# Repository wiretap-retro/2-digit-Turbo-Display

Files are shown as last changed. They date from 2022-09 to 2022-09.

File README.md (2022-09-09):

# 2 digit Turbo Display
This project is a ATTiny85-based turbo display for retro PC's. It displays 2 digits, for use in 8088 to 486 systems.

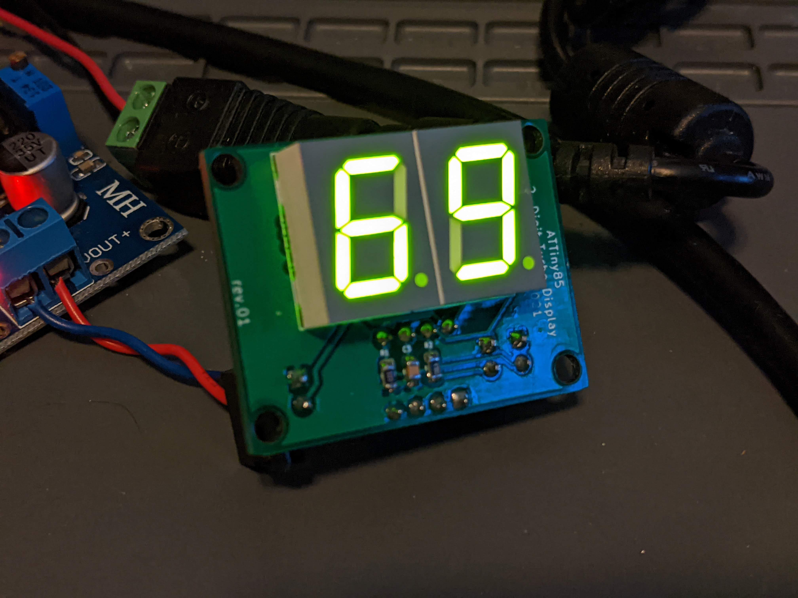
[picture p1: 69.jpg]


## Intro
I was wanting to do an ATTiny85 project and came up with a small 2-digit turbo display for use in my Intel 486 retro gaming PC. This design is pretty simple, easy to build and easy to program. If you have a dead turbo display or your case is missing one, this might be the right fit, as I have tested it on 3 different cases I have and it fits perfect into all of them. Mounting holes are different in nearly every case, so another mounting method may be necessary depending on your situation.
<br /><br />
Demo Video: https://youtu.be/Jka8PfParP4

## Building
* Order the PCB through your PCB fab of choice. (JLCPCB, PCBway, OSH Park, etc.)
* Order the components as listed in the BOM. Substitutions may be necessary depending on the chip/component shortages.
* On the back side and front side, solder the surface mount components first. Pay close attention to the orientation of the SOIC chips, as they are reversed from each other on the right and left.
* On the back side, solder the through-hole components next. I recommend using a socket for the ATTiny85 so you can easily install/remove it for programming.
* On the front side, solder the LED 7-segment displays.
* Soldering complete. Go to the Programming section below.

## Programming
I have included the turbo.ino file as an example. In the main program loop, you can change the "normal" and "turbo" variables to any 2 digit number to match the needs of your particular CPU speeds. The code is pretty well commented, so you can play around with it, adjust delays, make a startup animation, etc. To program the ATTiny85, you can look at one of the hundreds of guides online. For mine, I used a breadboard and another Arduino to do so. After it is programmed, place it in the DIP-8 socket of the turbo display PCB.

## Installation
* As noted in the intro section, this was designed to fit in the Baby-AT cases I have. It seems there was no standard back in the day for making these turbo displays or mounting them, so each case can be different. The digit size fits all mine that have 2-digit display holes, and at least one mounting hole fits on two of the cases. Only one screw is really necessary anyway since it is so small and light. You can secure it in your case with various methods. (tape, blu tack, 3d printed clip, etc.)
* Once mounted in the case, connect the 5V power to a Berg/Molex-->2x2.54mm header. 
* Connect the Turbo LED on your case to the TLED OUT pins.
* Use a female to female cable with 2x2.54mm connectors at each end to connect the motherboard's Turbo LED pins to the turbo display board's TLED IN. These are commonly found on Aliexpress, Amazon, and Ebay for use in Arduino/RPi projects.
* The turbo switch on your case should be connected to the computer's motherboard Turbo Switch pins.
* Turn on the PC and test it out!

## Design Notes
The design takes into account that your motherboard has turbo LED pins to drive switching of this display. I found this to be the most common feature among all motherboards, from the 8088 to 486. I probably own 25 different boards of this era, and they all have the pins to drive a turbo LED. This is the most universal design I could come up with.

## Other
This is an open source project. Feel free to do what you want with it.

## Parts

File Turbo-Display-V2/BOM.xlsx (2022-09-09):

ref | value | footprint | description
C1, C2 | 0.1uF | Capacitor_SMD:C_1206_3216Metric_Pad1.42x1.75mm_HandSolder | Unpolarized capacitor
C3 | 0.1uF | Capacitor_SMD:C_0805_2012Metric_Pad1.15x1.40mm_HandSolder | Unpolarized capacitor
DS1, DS2 | TDSG5150-N | TDSG5150N | LED Displays & Accessories 7-Seg Green 13 mm Common anode
J1, J2, J3 | 2x1 Pin Header | Connector_PinHeader_2.54mm:PinHeader_1x02_P2.54mm_Vertical | Generic connector, single row, 01x02, script generated (kicad-library-utils/schlib/autogen/connector/)
R1 | 10k | Resistor_SMD:R_0805_2012Metric_Pad1.15x1.40mm_HandSolder | Resistor
R2 | 470 | Resistor_SMD:R_0805_2012Metric_Pad1.15x1.40mm_HandSolder | Resistor
RN1, RN2 | 4816P-T01-471LF | SOIC127P762X240-16N | Res Thick Film NET 470 Ohm 2% 1.28W +/-100ppm/C ISOL Molded 16-Pin SOM Gull Wing SMD Automotive Tube
U1 | ATtiny85 | Package_DIP:DIP-8_W7.62mm | 20MHz, 8kB Flash, 512B SRAM, 512B EEPROM, debugWIRE, DIP-8
U2, U3 | SN74HC595DR | SamacSys_Parts:SOIC127P600X175-16N | 8-bit serial in/out Shift Register 3-State Outputs

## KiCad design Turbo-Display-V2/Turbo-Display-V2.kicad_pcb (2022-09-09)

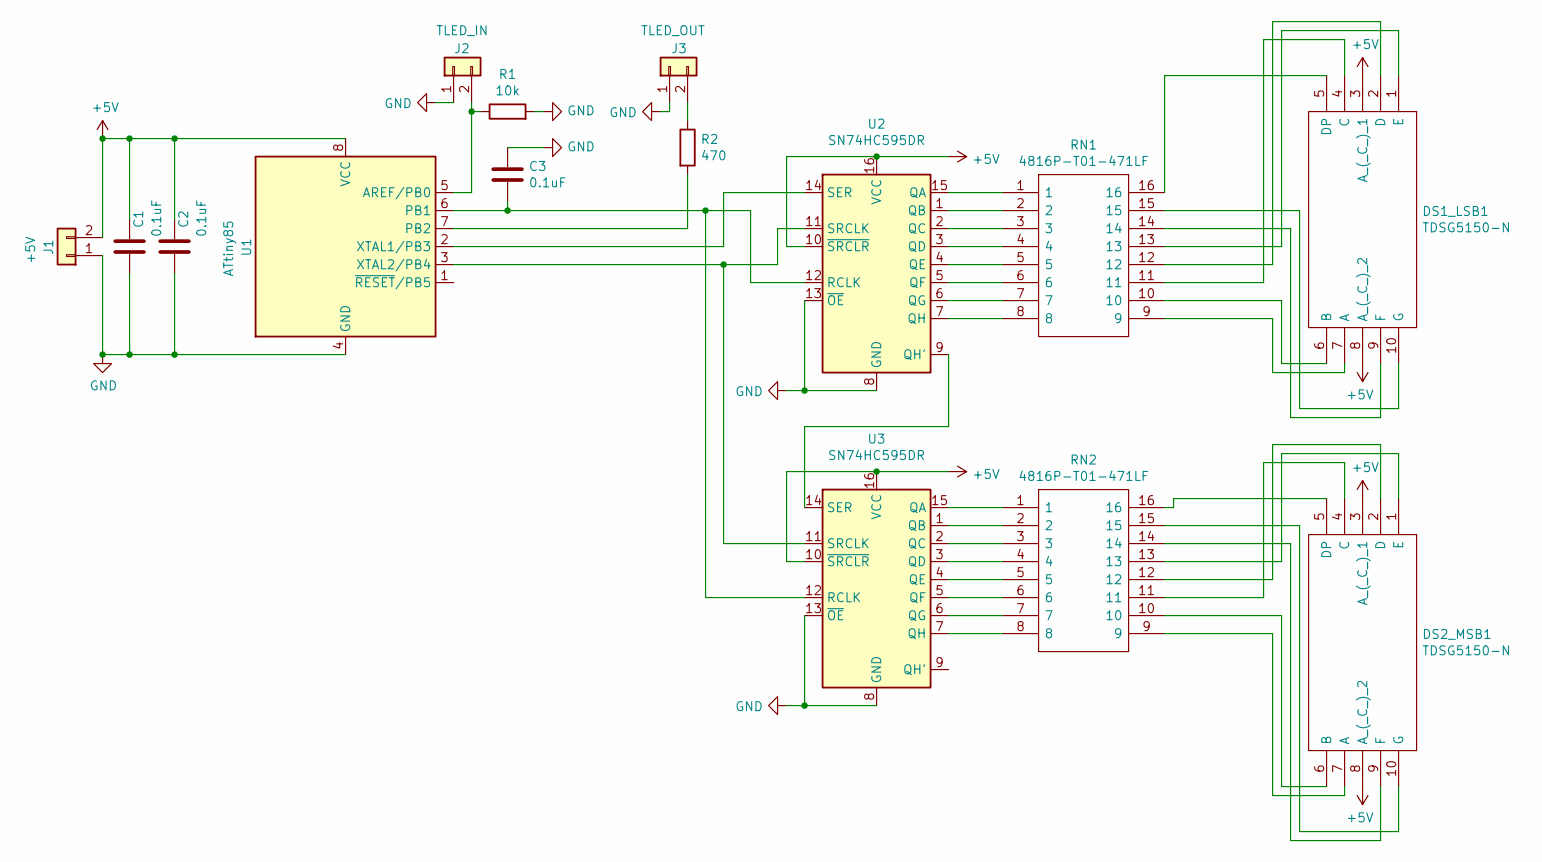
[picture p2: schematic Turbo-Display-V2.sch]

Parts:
C1, C2: 0.1uF; C_1206_3216Metric_Pad1.42x1.75mm_HandSolder
C3: 0.1uF; C_0805_2012Metric_Pad1.15x1.40mm_HandSolder
DS1_LSB1, DS2_MSB1: TDSG5150-N; TDSG5150N; Mouser Part Number 78-TDSG5150-N
J1: +5V; PinHeader_1x02_P2.54mm_Vertical
J2: TLED_IN; PinHeader_1x02_P2.54mm_Vertical
J3: TLED_OUT; PinHeader_1x02_P2.54mm_Vertical
R1: 10k; R_0805_2012Metric_Pad1.15x1.40mm_HandSolder
R2: 470; R_0805_2012Metric_Pad1.15x1.40mm_HandSolder
RN1, RN2: 4816P-T01-471LF; SOIC127P762X240-16N; Mouser Part Number 652-4816P-T1LF-470
U1: ATtiny85; DIP-8_W7.62mm
U2, U3: SN74HC595DR; SOIC127P600X175-16N

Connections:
+5V: C1.1, C2.1, DS1_LSB1.3 (A_(_C_)_1), DS1_LSB1.8 (A_(_C_)_2), DS2_MSB1.3 (A_(_C_)_1), DS2_MSB1.8 (A_(_C_)_2), J1.2, U1.8 (VCC), U2.10 (~SRCLR), U2.16 (VCC), U3.10 (~SRCLR), U3.16 (VCC)
GND: C1.2, C2.2, C3.1, J1.1, J2.1, J3.1, R1.2, U1.4 (GND), U2.8 (GND), U2.13 (~OE), U3.8 (GND), U3.13 (~OE)
unnamed: C3.2, U1.6 (PB1), U2.12 (RCLK), U3.12 (RCLK)
unnamed: DS1_LSB1.1 (E), RN1.13
unnamed: DS1_LSB1.2 (D), RN1.12
unnamed: DS1_LSB1.4 (C), RN1.11
unnamed: DS1_LSB1.5 (DP), RN1.16
unnamed: DS1_LSB1.6 (B), RN1.10
unnamed: DS1_LSB1.7 (A), RN1.9
unnamed: DS1_LSB1.9 (F), RN1.14
unnamed: DS1_LSB1.10 (G), RN1.15
unnamed: DS2_MSB1.1 (E), RN2.13
unnamed: DS2_MSB1.2 (D), RN2.12
unnamed: DS2_MSB1.4 (C), RN2.11
unnamed: DS2_MSB1.5 (DP), RN2.16
unnamed: DS2_MSB1.6 (B), RN2.10
unnamed: DS2_MSB1.7 (A), RN2.9
unnamed: DS2_MSB1.9 (F), RN2.14
unnamed: DS2_MSB1.10 (G), RN2.15
unnamed: J2.2, R1.1, U1.5 (AREF/PB0)
unnamed: J3.2, R2.1
unnamed: R2.2, U1.7 (PB2)
unnamed: RN1.1, U2.15 (QA)
unnamed: RN1.2, U2.1 (QB)
unnamed: RN1.3, U2.2 (QC)
unnamed: RN1.4, U2.3 (QD)
unnamed: RN1.5, U2.4 (QE)
unnamed: RN1.6, U2.5 (QF)
unnamed: RN1.7, U2.6 (QG)
unnamed: RN1.8, U2.7 (QH)
unnamed: RN2.1, U3.15 (QA)
unnamed: RN2.2, U3.1 (QB)
unnamed: RN2.3, U3.2 (QC)
unnamed: RN2.4, U3.3 (QD)
unnamed: RN2.5, U3.4 (QE)
unnamed: RN2.6, U3.5 (QF)
unnamed: RN2.7, U3.6 (QG)
unnamed: RN2.8, U3.7 (QH)
unnamed: U1.2 (XTAL1/PB3), U2.14 (SER)
unnamed: U1.3 (XTAL2/PB4), U2.11 (SRCLK), U3.11 (SRCLK)
unnamed: U2.9 (QH'), U3.14 (SER)

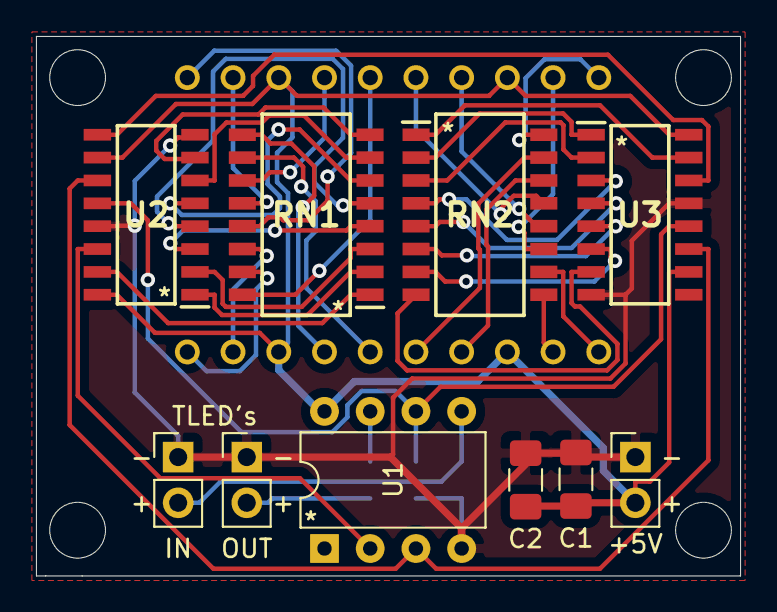
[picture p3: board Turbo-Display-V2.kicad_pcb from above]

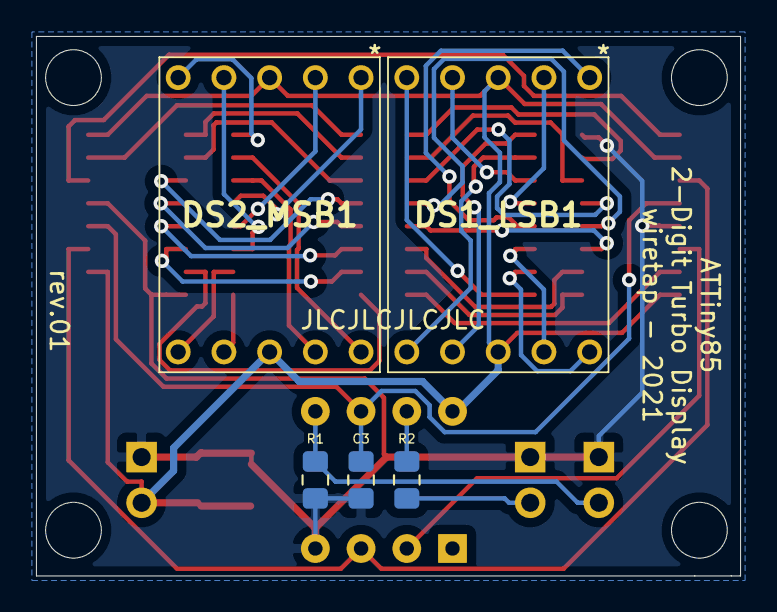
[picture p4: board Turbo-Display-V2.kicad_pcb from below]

Board: 2 copper layers, 39.1 x 30.0 mm, 15 parts (5 on the bottom side), 41 nets.

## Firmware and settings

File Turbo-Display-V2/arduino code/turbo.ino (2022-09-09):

/*
 *        ATTiny85
 * 2-Digit Turbo Display
 *     wiretap - 2021
 * 
 *     ATTiny85 Pinout
 *        ---------
 *        |1     8|--VCC
 * DATA---|2     7|--TLEDout
 * CLOCK--|3     6|--LATCH
 * GND----|4     5|--TLEDin
 *        ---------
 */

#define TLEDin 0  // Turbo LED from motherboard
#define LATCH 1   // To pin 12 of 74HC595
#define TLEDout 2 // Turbo LED output to PC case
#define DATA 3    // To pin 14 of 74HC595
#define CLOCK 4   // To pin 11 of 74HC595
// For turbo switch, utilize your existing case turbo switch hooked up to the motherboard, or keyboard command.

/* Fill array with segments 0 thru 9 (binary to decimal converted)
 * |--A--|
 * F     B
 * |--G--|
 * E     C
 * |--D--|
 *        H
 *  
 * Common Anode
 * 0 = HIGH (ON)
 * 1 = LOW (OFF)
 * 
 * GHCBAFED =  Disp  = DecEqv
 * 11000000 =  Zero  = 192
 * 11001111 =  One   = 207
 * 01100100 =  Two   = 100
 * 01000110 =  Three = 70
 * 01001011 =  Four  = 75
 * 01010010 =  Five  = 82
 * 01010000 =  Six   = 80
 * 11000111 =  Seven = 199
 * 01000000 =  Eight = 64
 * 01000010 =  Nine  = 66
 * 11111111 = All Off = 255
 * 
 */
int segments[] = {192, 207, 100, 70, 75, 82, 80, 199, 64, 66, 255}; 

void setup() {
  pinMode(TLEDin, INPUT);   // Read the LED state from the motherboard
  pinMode(TLEDout, OUTPUT); // Turns on/off the turbo LED on your PC case
  pinMode(LATCH, OUTPUT);   // Latch to shift register is an output
  pinMode(CLOCK, OUTPUT);   // Clock to shift register is an output
  pinMode(DATA, OUTPUT);    // Data to shift register is an output
}

// Main program loop
void loop() {  
  int normal = 33;                     // Set your non-turbo frequency to display here
  int turbo = 66;                     // Set your turbo frequency to display here
  int LEDstate = digitalRead(TLEDin); // Read turbo LED from motherboard and call it LEDstate
  
  if (LEDstate == LOW) {
    digitalWrite(TLEDout, LOW); // If turbo LED from motherboard is off, turn off turbo LED
    displayNumber(normal);      // If turbo LED from motherboard is off, display non-turbo frequency
  } else {
    digitalWrite(TLEDout, HIGH);  // If turbo LED from motherboard is on, turn on PC case turbo LED
    displayNumber(turbo);         // If turbo LED from motherboard is on, display turbo frequency
  }
delay(500);
}

// Function to break down the number to display by digit
void displayNumber(int n) {
  int left, right = 0;
  if (n < 10) {
    digitalWrite(LATCH, LOW);
    shiftOut(DATA, CLOCK, LSBFIRST, segments[10]);  // Send zero to the left digit
    shiftOut(DATA, CLOCK, LSBFIRST, segments[n]);  // Send number <10 to the right digit
    digitalWrite(LATCH, HIGH);
    delay(500);
  }
  else if (n >= 10) {
    right = n % 10; // Remainder
    left = n / 10;  // Quotient
    digitalWrite(LATCH, LOW);
    shiftOut(DATA, CLOCK, LSBFIRST, segments[left]);   // Send 10's digit to the left digit
    shiftOut(DATA, CLOCK, LSBFIRST, segments[right]);  // Send 1's digit to the right digit
    digitalWrite(LATCH, HIGH);
    delay(500);
  }
}
